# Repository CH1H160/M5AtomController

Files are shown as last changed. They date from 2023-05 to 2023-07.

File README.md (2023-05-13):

# M5AtomController
Controller capable of wireless communication by ESP-NOW and wired communication by USB serial
<p align="center">

</p>

## Overview
What kind of controller do you usually use? There are many for PC and games. And now most of them are wireless.
It's very convenient, but it has its problems. For example, at an exhibition hall, bad reception. :weary: 
<p align="center">

</p>

This work can solve such problems. Wireless communication is usually performed with ESP-NOW, and it is possible to immediately switch to serial communication simply by connecting USB.
This is a controller that supports many "Makers" :smiley:
<p align="center">

</p>

## BOM
If you own a 3D printer, print it yourself. 
FYI, if you don't have one, you can order it at JLCPCB, etc.

<p align="center">

</p>

|  #  | Part | Item |  Qty  | Link |
| --- | --- | --- | :---: | --- |
| 1 | ATOM Matrix | ESP32 Development Kit | 1 | [M5Stack](https://shop.m5stack.com/products/atom-matrix-esp32-development-kit) , [SwitchScience](ssci.to/6260) |
| 2 | ATOM TailBAT | Battery | 1 | [M5Stack](https://shop.m5stack.com/products/atom-tailbat) , [SwitchScience](ssci.to/6348) |
| 3 | [M5AtomControllerBoard](electronics/) | Circuit board | 1 | [JLCPCB](https://jlcpcb.com/) |
| 4 | [M5AtomControllerMain](3d-model/M5AtomControllerMain.stl/) | 3D print parts | 1 | [JLCPCB](https://jlcpcb.com/) |
| 5 | [M5AtomControllerCover](3d-model/M5AtomControllerCover.stl) | 3D print parts | 1 | [JLCPCB](https://jlcpcb.com/) |
| 6 | [M5AtomControllerCrossKey](3d-model/M5AtomControllerCrossKey.stl) | 3D print parts | 1 | [JLCPCB](https://jlcpcb.com/) |
| 7 | [M5AtomControllerButton](3d-model/M5AtomControllerButton.stl) | 3D print parts | 2 | [JLCPCB](https://jlcpcb.com/) |
| 8 | Famicom button | Conductive rubber pad | 1 | [Amazon](www.amazon.co.jp/dp/B01MXDIUC3) |
| 9 | SCREW 2.2 x 5.5 | Tapping screw | 3 | [秋月電子通商](https://akizukidenshi.com/catalog/g/gP-10223/) |
| 10  | PH-1X20SG | Pin header | 1 | [秋月電子通商](https://akizukidenshi.com/catalog/g/gC-16590/) |

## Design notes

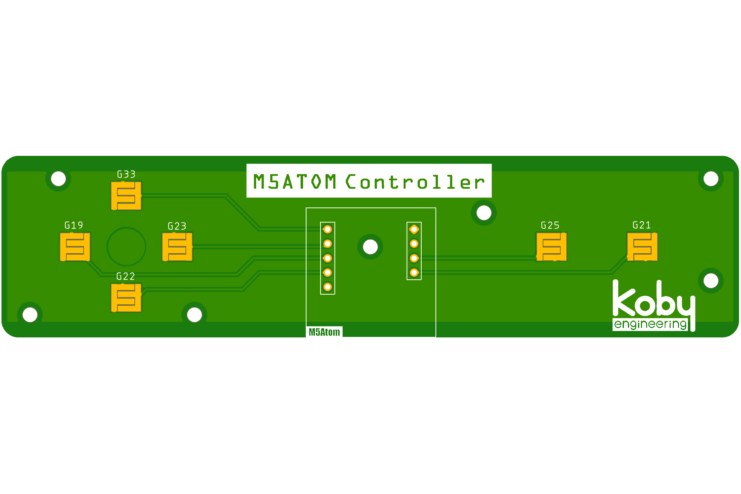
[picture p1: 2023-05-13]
electronics/M5AtomControllerBoard.png

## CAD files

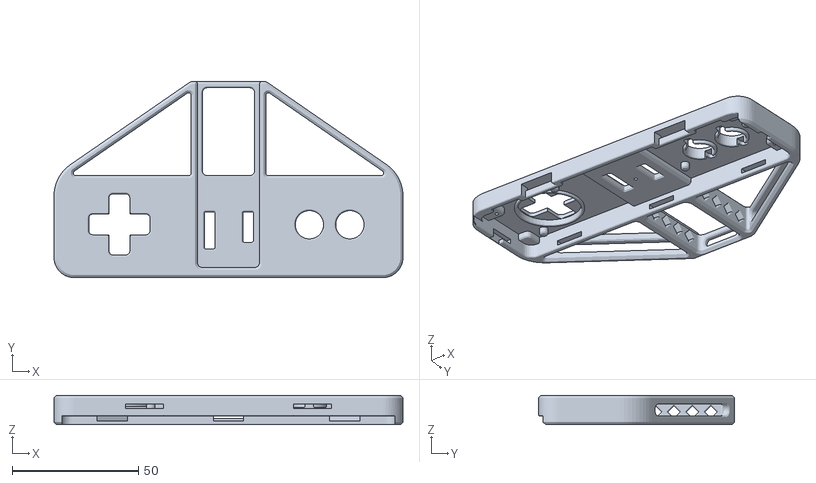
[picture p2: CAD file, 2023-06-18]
3d-model/M5AtomControllerMain.stl
138.0 x 77.6 x 11.6

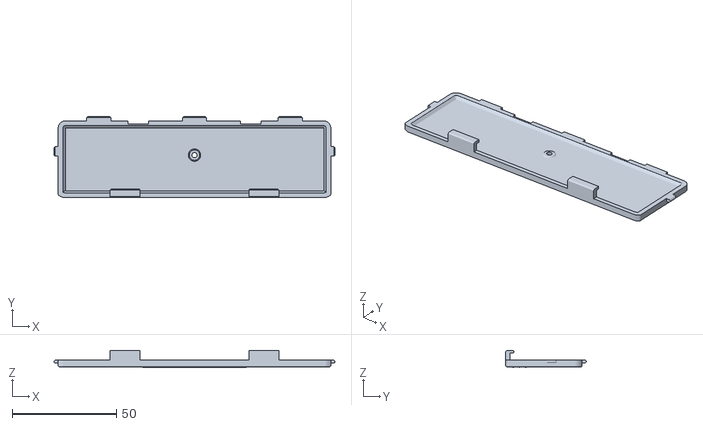
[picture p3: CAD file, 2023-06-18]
3d-model/M5AtomControllerCover.stl
135.0 x 38.8 x 8.28

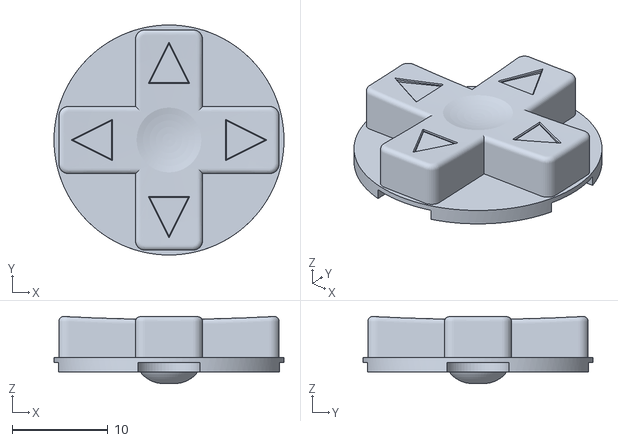
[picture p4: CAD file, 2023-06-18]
3d-model/M5AtomControllerCrossKey.stl
24.0 x 24.0 x 6.99

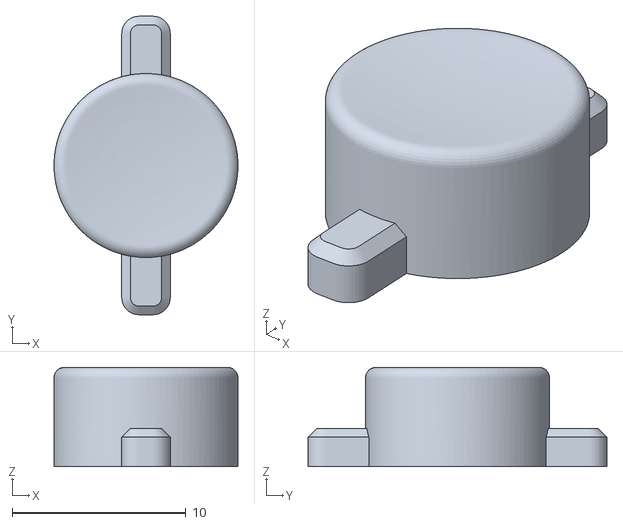
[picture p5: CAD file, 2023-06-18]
3d-model/M5AtomControllerButton.stl
10.6 x 17.2 x 5.72

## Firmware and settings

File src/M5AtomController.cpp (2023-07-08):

/**
 * @file M5AtomController.cpp
 * @brief Controller capable of wireless communication by ESP-NOW and wired communication by USB serial
 * @author Ryota Kobayashi
 * @version  V0.1.0
 * @date May 16, 2023
 * @details Numeric data is sent according to the input of the controller. 
 *          During ESP-NOW, the display turns blue upon successful transmission.
 * @note When using ESP-NOW, change the destination Mac address. 
 *       When using USB serial, match the baud rate.
 */

#include "M5AtomController.h"
#include <WiFi.h>
#include <esp_now.h>

//! Pin setting
const uint8_t PIN_TX = 26;
const uint8_t PIN_RX = 32;

const uint8_t PIN_UP = 33;
const uint8_t PIN_DOWN = 22;
const uint8_t PIN_LEFT = 19;
const uint8_t PIN_RIGHT = 23;
const uint8_t PIN_A = 21;
const uint8_t PIN_B = 25;
const uint8_t PIN_C = 39;

const uint8_t PIN_COUNT = 7;
const uint8_t PIN_ARRAY[PIN_COUNT] = { PIN_UP, PIN_DOWN, PIN_LEFT, PIN_RIGHT, PIN_A, PIN_B, PIN_C }; 

//! Led color
CRGB led_color = CRGB::Red;

/**
* @brief ESP-NOW send callback function
* @param[in] mac_addr Mac address
* @param[in] status Send result
* @details Change led color on successful transmission
*/
static void on_data_sent(const uint8_t *mac_addr, esp_now_send_status_t status) {

  led_color = (status == ESP_NOW_SEND_SUCCESS) ? CRGB::Blue : CRGB::Red;
}

/**
* @brief Constructor
*
* @param[in] mac_addr Mac address
*/
M5AtomController::M5AtomController(){

}

/**
* @brief Start connection
* @param[in] baudrate USB serial baudrate
* @return Success or failure of connection
*/
bool M5AtomController::begin(const uint8_t *mac_addr, const uint32_t baudrate){

  memcpy(slave_address, mac_addr, 6);

  M5.begin(true, false, true);

  // Make the display a red square
  led_square(CRGB::Green);

  // Pin setting
  for(int i=0; i<PIN_COUNT; i++){
    pinMode(PIN_ARRAY[i], INPUT_PULLUP);
  }

  // Serial setting
  Serial.begin(baudrate);
  Serial1.begin(baudrate, SERIAL_8N1, PIN_RX, PIN_TX);

  // WiFi setting
  WiFi.mode(WIFI_STA);
  WiFi.disconnect();

  // ESP-NOW setting
  esp_now_init();
  esp_now_peer_info_t peerInfo;
  memcpy(peerInfo.peer_addr, slave_address, 6);
  peerInfo.channel = 0;
  peerInfo.encrypt = false;

  esp_now_register_send_cb(on_data_sent);

  if (esp_now_add_peer(&peerInfo) != ESP_OK) {
    return false;
  }
  return true;
}

/**
* @brief Data transmission
* @param[in] value Serial data
*/
void M5AtomController::send(uint8_t value){

  uint8_t data[1] = {value};

  // Serial wired transmission
  Serial.write(value);
  Serial1.write(value);

  // ESP-NOW wireless transmission
  esp_now_send(slave_address, data, sizeof(data));
}

/**
* @brief Update state
*
*/
void M5AtomController::update(void){

  uint8_t transition_count = 0;

  // Check the input one by one and send the data
  for(uint8_t i=0; i<PIN_COUNT; i++){
    if (!digitalRead(PIN_ARRAY[i])){
      // transmission
      send(i);

      // Turn on the LED and show the display
      show_display(i, led_color);

      transition_count++;
    }
  }

  if(transition_count == 0){
    // Show green square when idle
    led_square(CRGB::Green);
    
    transition_count = 0;
  }
  
}

/**
* @brief Show display according to mode
* @param[in] led_mode Button pressed state
* @param[in] color display led color
*/
void M5AtomController::show_display(uint8_t led_mode, CRGB color){
  
  switch (led_mode){
    case 0:
      led_arrow_up(color);
      break;
    case 1:
      led_arrow_down(color);
      break;
    case 2:
      led_arrow_left(color);
      break;
    case 3:
      led_arrow_right(color);
      break;
    case 4:
      led_text_a(color);
      break;
    case 5:
      led_text_b(color);
      break;
    case 6:
      led_text_c(color);
      break;
  }
  M5.update();
}

/**
* @brief Show up arrow on display
* @param[in] color led color
*/
void M5AtomController::led_arrow_up(CRGB color){
  
  M5.dis.clear();
  M5.dis.drawpix(2, color);
  M5.dis.drawpix(7, color);
  M5.dis.drawpix(10, color);
  M5.dis.drawpix(12, color);
  M5.dis.drawpix(14, color);
  M5.dis.drawpix(16, color);
  M5.dis.drawpix(17, color);
  M5.dis.drawpix(18, color);
  M5.dis.drawpix(22, color);
  
}

/**
* @brief Show up down on display
* @param[in] color led color
*/
void M5AtomController::led_arrow_down(CRGB color){
  
  M5.dis.clear();
  M5.dis.drawpix(2, color);
  M5.dis.drawpix(6, color);
  M5.dis.drawpix(7, color);
  M5.dis.drawpix(8, color);
  M5.dis.drawpix(10, color);
  M5.dis.drawpix(12, color);
  M5.dis.drawpix(14, color);
  M5.dis.drawpix(17, color);
  M5.dis.drawpix(22, color);
  
}

/**
* @brief Show left arrow on display
* @param[in] color led color
*/
void M5AtomController::led_arrow_left(CRGB color){
  
  M5.dis.clear();
  M5.dis.drawpix(2, color);
  M5.dis.drawpix(8, color);
  M5.dis.drawpix(10, color);
  M5.dis.drawpix(11, color);
  M5.dis.drawpix(12, color);
  M5.dis.drawpix(13, color);
  M5.dis.drawpix(14, color);
  M5.dis.drawpix(18, color);
  M5.dis.drawpix(22, color);
  
}

/**
* @brief Show right arrow on display
* @param[in] color led color
*/
void M5AtomController::led_arrow_right(CRGB color){
  
  M5.dis.clear();
  M5.dis.drawpix(2, color);
  M5.dis.drawpix(6, color);
  M5.dis.drawpix(10, color);
  M5.dis.drawpix(11, color);
  M5.dis.drawpix(12, color);
  M5.dis.drawpix(13, color);
  M5.dis.drawpix(14, color);
  M5.dis.drawpix(16, color);
  M5.dis.drawpix(22, color);
  
}

/**
* @brief Show a square on the display
* @param[in] color led color
*/
void M5AtomController::led_square(CRGB color){
  
  M5.dis.clear();
  M5.dis.drawpix(6, color);
  M5.dis.drawpix(7, color);
  M5.dis.drawpix(8, color);
  M5.dis.drawpix(11, color);
  M5.dis.drawpix(13, color);
  M5.dis.drawpix(16, color);
  M5.dis.drawpix(17, color);
  M5.dis.drawpix(18, color);
  
}

/**
* @brief Show the text A on the display
* @param[in] color led color
*/
void M5AtomController::led_text_a(CRGB color){
  
  M5.dis.clear();
  M5.dis.drawpix(1, color);
  M5.dis.drawpix(3, color);
  M5.dis.drawpix(6, color);
  M5.dis.drawpix(7, color);
  M5.dis.drawpix(8, color);
  M5.dis.drawpix(11, color);
  M5.dis.drawpix(13, color);
  M5.dis.drawpix(16, color);
  M5.dis.drawpix(17, color);
  M5.dis.drawpix(18, color);
  M5.dis.drawpix(22, color);
  
}

/**
* @brief Show the text B on the display
* @param[in] color led color
*/
void M5AtomController::led_text_b(CRGB color){
  
  M5.dis.clear();
  M5.dis.drawpix(2, color);
  M5.dis.drawpix(3, color);
  M5.dis.drawpix(6, color);
  M5.dis.drawpix(8, color);
  M5.dis.drawpix(12, color);
  M5.dis.drawpix(13, color);
  M5.dis.drawpix(16, color);
  M5.dis.drawpix(18, color);
  M5.dis.drawpix(22, color);
  M5.dis.drawpix(23, color);
  
}
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

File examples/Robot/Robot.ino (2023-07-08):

/**
 * @file Robot.ino
 * @brief A sample of a robot that moves with controller communication.
 * @author Ryota Kobayashi
 * @date July 8, 2023
 */
#include <esp_now.h>
#include <WiFi.h>

bool is_wired = true;

//! controller button
enum button {
  UP,
  DOWN,
  LEFT,
  RIGHT,
  A,
  B,
  C
};

//! ESP-NOW receive callback
void onReceive(const uint8_t* mac_addr, const uint8_t* data, int data_len) {

  is_wired = false;
  action(data[0]);
  delay(100);
  is_wired = true;
}

//! Movement when command is received
void action(uint8_t input_data){
  switch (input_data){
    case button::UP:
      // command response
      break;
    case button::DOWN:
      // command response
      break;
    case button::LEFT:
      // command response
      break;
    case button::RIGHT:
      // command response
      break;
    case button::A:
      // command response
      break;
    case button::B:
      // command response
      break;
    case button::C:
      // command response
      break;
  }
}

/**
* Arduino standard setup function
* put your setup code here, to run once
*/
void setup(){
  Serial1.begin(115200, SERIAL_8N1, 32, 33);
  WiFi.mode(WIFI_STA);
  WiFi.disconnect();
  esp_now_init();
  esp_now_register_recv_cb(onReceive);
}

/**
* Arduino standard loop function
* put your main code here, to run repeatedly
*/
void loop(){
  if(is_wired){
    if ( Serial1.available() ) {
      action(Serial1.read());
    }
  }
}

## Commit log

2023-05-13 add stl file
    [M5AtomControllerButton.stl, M5AtomControllerCover.stl, M5AtomControllerCrossKey.stl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]
2023-05-13 add gerber file
2023-05-13 add arduino file
2023-05-16 fix button model
    [M5AtomControllerButton.stl]
2023-06-18 optimize shape
    [M5AtomControllerButton.stl, M5AtomControllerCover.stl, M5AtomControllerCrossKey.stl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]
2023-07-08 add robot sample
